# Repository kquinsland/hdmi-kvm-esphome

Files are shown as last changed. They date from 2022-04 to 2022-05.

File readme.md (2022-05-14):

# `uart_kvm` custom component for ESPHome

This custom component allows for basic control over a generic 8:1 HDMI2.0 KVM switch.
Specifically developed for model number [`PX-UHDKVM801-2.0`](https://www.aliexpress.com/item/1005003927404402.html).

Photos of the internals can be found [on my personal site](https://karlquinsland.com/hdmi-kvm-teardown-and-esphome/).

When working, you should get a device page in Home Assistant like this:

<!-- markdownlint-disable-next-line MD045 -->
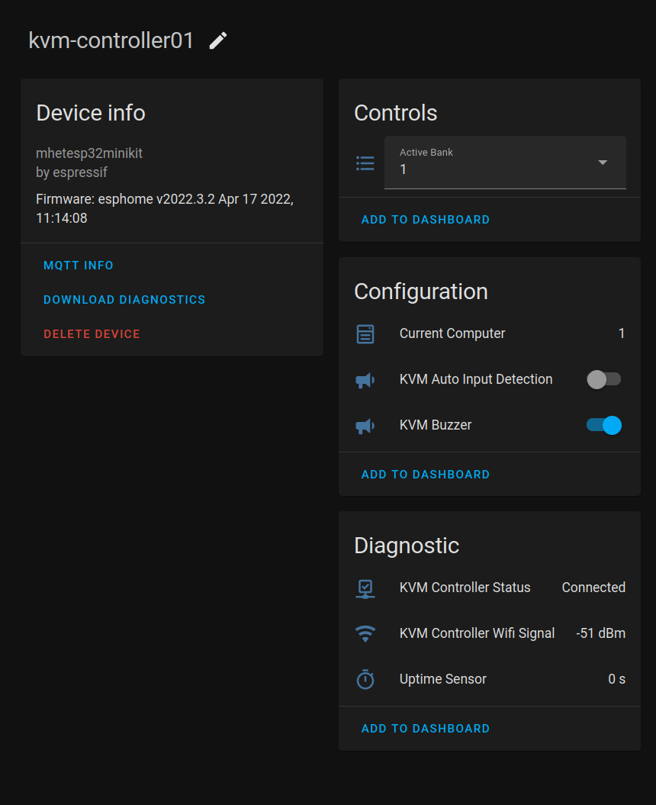
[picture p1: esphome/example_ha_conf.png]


## Using the component

**Note:** It is possible to get _basic_ control over the KVM without this custom component! ESPHome has _native_ support for _writing_ to a UART. If you only need to tell the KVM what to do then you can use the native [`uart.write`](https://esphome.io/components/uart.html#uart-write-action) call!

However, if  you also want to probe the KVM to get the current active input bank, you will need to _read_ from the UART which can't be done with the native UART component. That's where this custom component comes into play :).

To load this custom component in your ESPHome configuration, you need to use the [`external_components`](https://esphome.io/components/external_components.html) block like so:

```yaml
external_components:
  - source:
      type: git
      url: https://github.com/kquinsland/hdmi-kvm-esphome
    components: [ uart_kvm ]
```

If you have any issues, try to remove the local cache:

<!-- markdownlint-disable-file MD014 -->
```shell
$ rm -rf .esphome/external_components
```

## Example YAML

This is not a _complete_ YAML file for ESPHome but it does illustrate how to use the custom component and to control the KVM directly with `uart.write` for the various functionalities that the custom component does NOT implement:

```yaml
esphome:
  on_boot:
    priority: 600
    then:
      # Buzzer on is helpful for testing and to know when an automation triggers a change
      - switch.turn_on: sw_tmpl_buzzer
      # I do not want the KVM to automatically switch to any new active HDMI cable
      - switch.turn_off: sw_tmpl_auto_input

# See: https://esphome.io/components/external_components.html
# Will be cached in .esphome/external_components/
##
external_components:
  - source:
      type: git
      url: https://github.com/kquinsland/hdmi-kvm-esphome
    components: [ uart_kvm ]

##
# Expose a dropdown/select to the user via HA
# See: https://esphome.io/components/select/template.html
##
select:
  - platform: template
    id: tmpl_sel_active_port
    name: "Active Bank"
    optimistic: false
    # Create one option for each host the KVM is to control
    # You can use any string you like but the `set_active_bank()` requires an `int` so
    #   choose the strings in the select wisely!
    # Create an entry for each input bank you wish to be able to switch between.
    # E.G.: If you only have 5 hosts attached to an 8 bank switch, you can safely
    #   leave options for 6,7,8 off.
    # In testing the KVM silently ignores commands to switch to an input bank beyond
    #   what the switch supports. E.G.: telling an 8 port KVM to make bank 10 active 
    #    does nothing.
    ##
    options:
      - "1"
      - "2"
      - "3"
      - "4"
      - "5"
      - "6"
      - "7"
      - "8"
    set_action:
      then:
        lambda: |-
          // ESPHome/HA use strings in select components. atoi() fixes this for us :)
          int bank = atoi(x.c_str());
          id(kvm1).set_active_bank(bank);
    # We poll the uart to get the current port
    # Note: ESPHome polls get_active_bank() every several seconds. Unless we actively tell ESPHome to
    #   re-run this lambda as soon as the KVM active input bank changes, this value will lag behind reality
    lambda: |-
      int active = id(kvm1).get_active_bank();
      return to_string(active);

# The initial documentation that the seller provided did not define a way to inquire about buzzer active state or active input chase behavior so we can implement this with standard `uart.write` rather than in custom c++
switch:
  - platform: template
    id: sw_tmpl_buzzer
    name: "${friendly_name_short} Buzzer"
    icon: "mdi:bullhorn"
    entity_category: "config"
    device_class: "switch"
    optimistic: True
    # I don't know how to confirm the state of things so we must assume that sending the "off" command will be enough to turn it off. In testing, sending the "off" command is reliable.
    # If this was not the case, then we could change how things work in HA: instead of a switch
    #   the user will see 2 buttons: one for on, the other for off.
    assumed_state: false
    turn_on_action:
        # Note: the KVM does a short chirp to indicate that it is on
      - uart.write: [0xAA, 0xBB, 0x03, 0x02, 0x01, 0xEE]
    turn_off_action:
      - uart.write: [0xAA, 0xBB, 0x03, 0x02, 0x00, 0xEE]

  - platform: template
    id: sw_tmpl_auto_input
    name: "${friendly_name_short} Auto Input Detection"
    icon: "mdi:bullhorn"
    entity_category: "config"
    device_class: "switch"
    optimistic: True
    assumed_state: False
    turn_on_action:
      - uart.write: [0xAA, 0xBB, 0x03, 0x81, 0x01, 0xEE]
    turn_off_action:
      - uart.write: [0xAA, 0xBB, 0x03, 0x81, 0x00, 0xEE]

uart:
  # We want to impersonate the remote/handset by injecting via the HTX pin which is mapped to 17
  tx_pin: GPIO17
  # Likewise, if the motor controller sends anything to the remote, we _also_ want to hear it.
  rx_pin: GPIO16
  # bog standard 9600 8n1
  baud_rate: 9600

# Load up __init.py__
uart_kvm:
    id: kvm1
    active_bank:
      id: kvm1_bank
      name: "Current Computer"
      # We will expose this to HA through the template select above
      internal: false
      on_value:
        then:
          - lambda: |-
              // Tell ESPHome to refresh the value for the select so it does not lag by several seconds
              id(tmpl_sel_active_port).update();

```

### UART + Component

You will need a TTL <-> RS232 adapter hooked up to an ESP module. I have had a lot of trouble with the cheap MAX232 clone dongles on amazon so you absolutely should do basic loopback tests and confirm signal / voltage levels with an oscilloscope if you are having trouble getting this to work!

## PCB and enclosure

Because "scope-creep" is my middle name, I created a simple PCB and enclosure for an ESP32 module and `TTL` <-> `UART` module.
Details on both the PCB and enclosure can be found in the [`hardware`](./hardware/readme.md) folder.

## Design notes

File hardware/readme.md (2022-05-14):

# Hardware

The PCB and case are designed to be 1U in height. This also makes it pretty easy to secure to a basic power brick.
The PCB  can be powered via USB or via 12V DC. I wasn't sure if I was going to power the module off of one of the spare USB ports on the KVM or if I wanted to bundle the controller and main power supply so i could have one cable bundle going towards the KVM. I opted for the latter and decided to secure the enclosure to the power supply.

<!-- markdownlint-disable-next-line MD045 -->
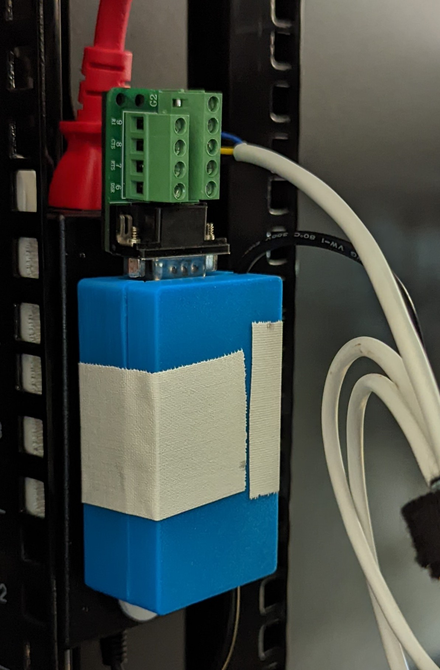
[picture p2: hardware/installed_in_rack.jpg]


The "DC out" cable leaves the enclosure right next to the DB9 port where the serial and power cables are combined with some cable ties before being routed to the KVM on the front of the rack.

## PCB

If you want to edit the pcb, the KiCad 6 files are included subject to [the license terms](../LICENSE.md).

The ESP32 module comes from [this](https://github.com/r0oland/ESP32_mini_KiCad_Library) library. Thanks to [r0oland](https://github.com/r0oland) for that library!

<!-- markdownlint-disable-next-line MD045 -->
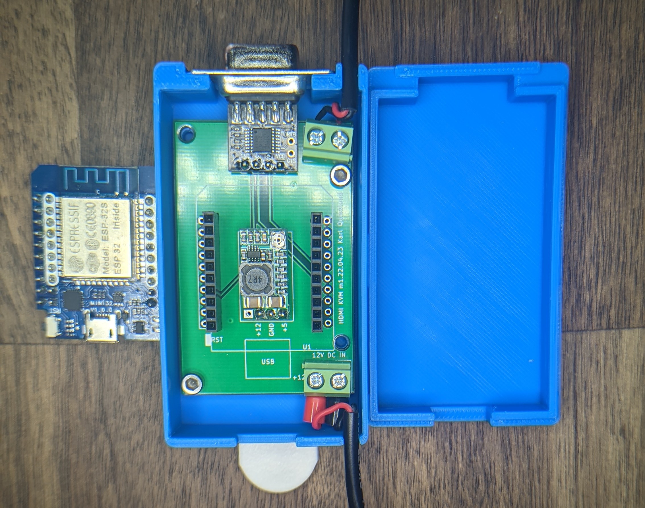
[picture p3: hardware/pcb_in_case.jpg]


### BOM

The PCB is secured to the enclosure with some 4mm M3 screws I had laying around.
The primary components on the PCB are:

- [D1 Mini style ESP32 chip](https://www.aliexpress.com/item/2251832633593063.html)
- [Configurable DC Buck converter module](https://www.aliexpress.com/item/32833398811.html). This steps the 12V dc from the KVM power supply down to the 5V for the ESP32 module.
- [Ultra Compact RS232 to TTL Converter with Female DB9 (3.3V to 5V)](https://www.amazon.com/gp/product/B00OPTOKI0/)

#### gerber

If you want to make zero changes, the [gerber files are included](./pcb/hdmi-kvm/export/2022.04.23.zip) and are subject to [the license terms](../LICENSE.md).

The gerber files / KiCad project are set up for use with JLCPCB but probably would work as-is with other PCB fab houses, too.

## Enclosure

It's not my best work but it works. I printed with my "fast, not accurate" profile so the snaps that are meant to keep the lid attached to the rest of the body don't work that well; this is the reason for the white tape in the picture.

You should be OK if you print slower but STEP files for both the [PCB](./pcb/hdmi-kvm/hdmi-kvm.step) and [enclosure](./enclosure/kvm-controller-enclosure.step) are included - subject to [the license terms](../LICENSE.md),

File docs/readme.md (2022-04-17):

Soon after ordering the switch, the seller provided me _basic_ information about how to control the KVM over RS232 and TCP:

[`01.png`](./from_seller/01.png)

[`02.jpg`](./from_seller/02.jpg)

I was able to plug the unique byte string `0xAA 0xBB 0x03` into google and found some additional documentation:

[`4x1-DVI-KVM-CommunicationProtocol.pdf`](./from_google/4x1-DVI-KVM-CommunicationProtocol.pdf)

[`16x1-hdmi-communication-protocol.pdf`](./from_google/16x1-hdmi-communication-protocol.pdf)

Only after I had done about 75% of the ESPHome custom component code did the seller provide me with [`8x1 KVM product integration information.zip`](./from_seller/8x1%20KVM%20product%20integration%20information.zip).

The `8x1 KVM product integration information` folder is the zip extracted. It contains additional software that appears to support more functionality than the basic serial documentation!

It shouldn't be super difficult to run the program and monitor the UART with either WireShark or a logic analyzer to figure out how to do the "program exclusive" things like:

- Change the IP address
- Change the LED display timeout

I don't need this functionality for my purposes so I'm not going to bother... 

I did dump the strings [`Controler.exe.strings`](./from_seller/8x1%20KVM%20product%20integration%20information/8x1-HDMI-Switch-Controler/Controler.exe.strings) and file hashes [`sha256sums.txt`](./from_seller/8x1%20KVM%20product%20integration%20information/8x1-HDMI-Switch-Controler/sha256sums.txt) just for posterity.

If you do manage to reverse engineer the magic UART commands to adjust TCP/IP config and other settings, please do share! PRs welcome :D.

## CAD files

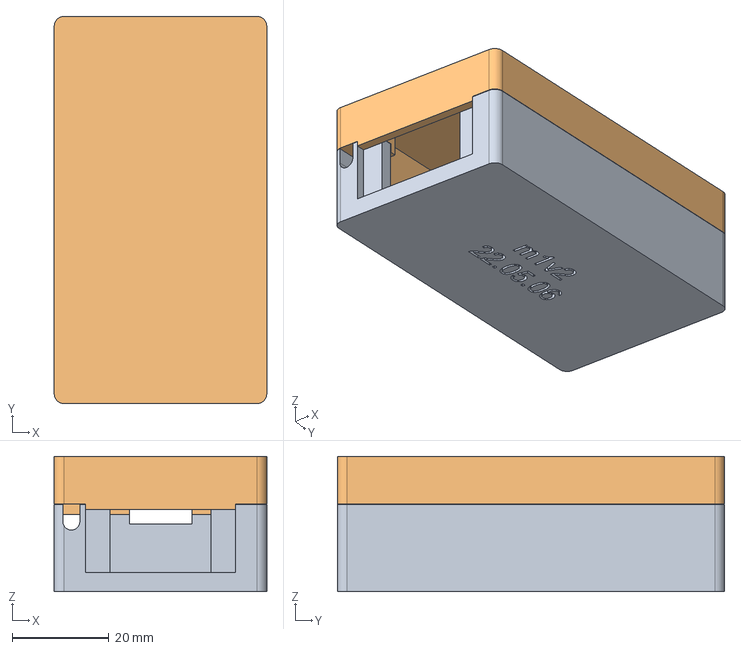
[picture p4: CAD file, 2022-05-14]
hardware/enclosure/kvm-controller-enclosure.step
44.0 x 80.1 x 28.0 mm

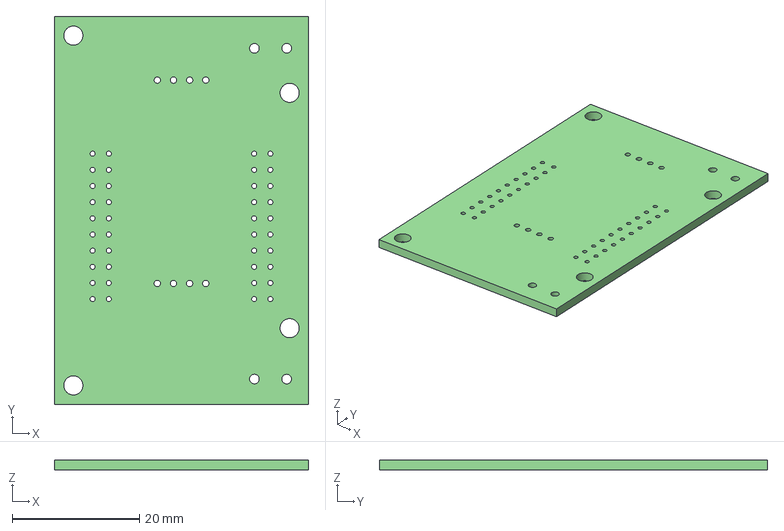
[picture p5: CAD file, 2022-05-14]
hardware/pcb/hdmi-kvm/hdmi-kvm.step
40.0 x 61.0 x 1.60 mm

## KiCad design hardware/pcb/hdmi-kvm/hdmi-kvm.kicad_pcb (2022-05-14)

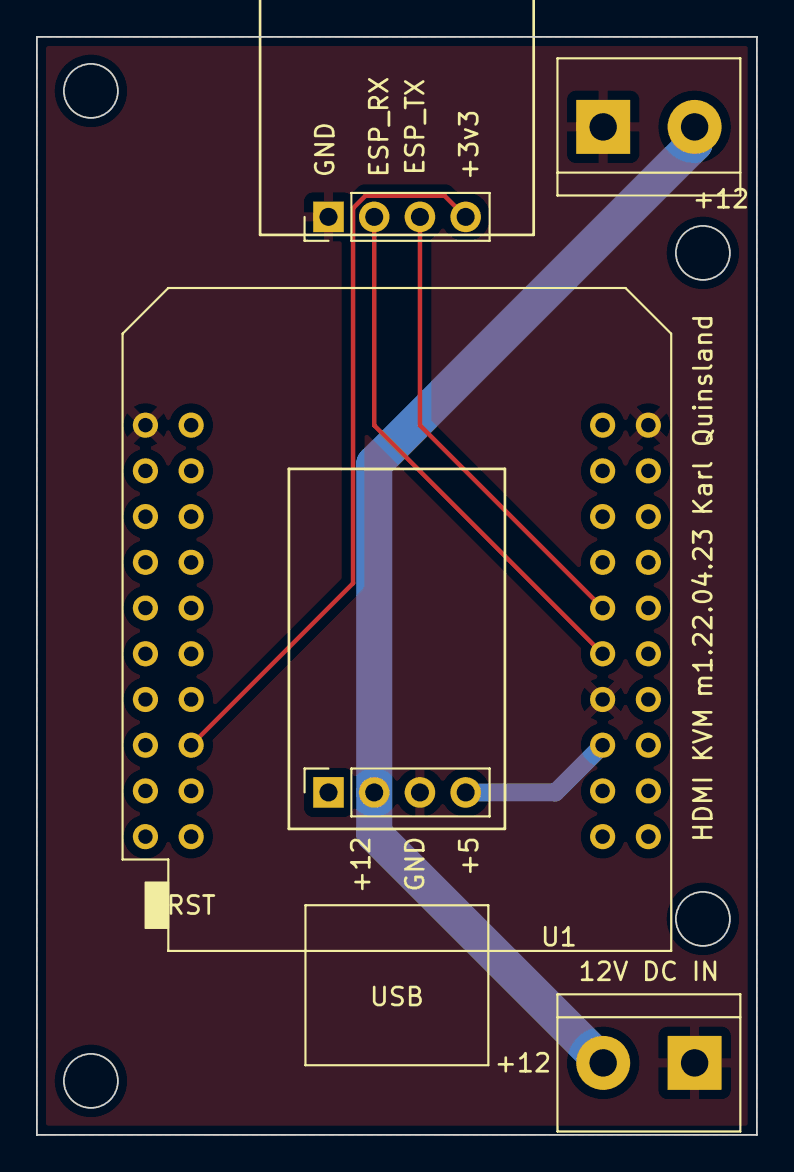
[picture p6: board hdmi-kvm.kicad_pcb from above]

Board: 2 copper layers, 40.0 x 61.0 mm, 5 parts (0 on the bottom side), 6 nets.

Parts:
J1: 12V DC IN; TerminalBlock_bornier-2_P5.08mm
J2: 12V DC OUT; TerminalBlock_bornier-2_P5.08mm
J3: DC_BUCK_CONN; PinSocket_1x04_P2.54mm_Vertical
J4: Conn_01x04_Male; PinHeader_1x04_P2.54mm_Vertical
U1: mini_esp32; ESP32_mini

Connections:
+3V3: J4.4, U1.16 (3V3)
+5V: J3.4, U1.35 (VCC_(USB))
+12V: J1.2, J2.2, J3.2
ESP_RX: J4.2, U1.31 (IO_16/D4)
ESP_TX: J4.3, U1.29 (IO_17/D3)
GND: J1.1, J2.1, J3.3, J4.1, U1.1 (GND), U1.22 (GND), U1.33 (GND)

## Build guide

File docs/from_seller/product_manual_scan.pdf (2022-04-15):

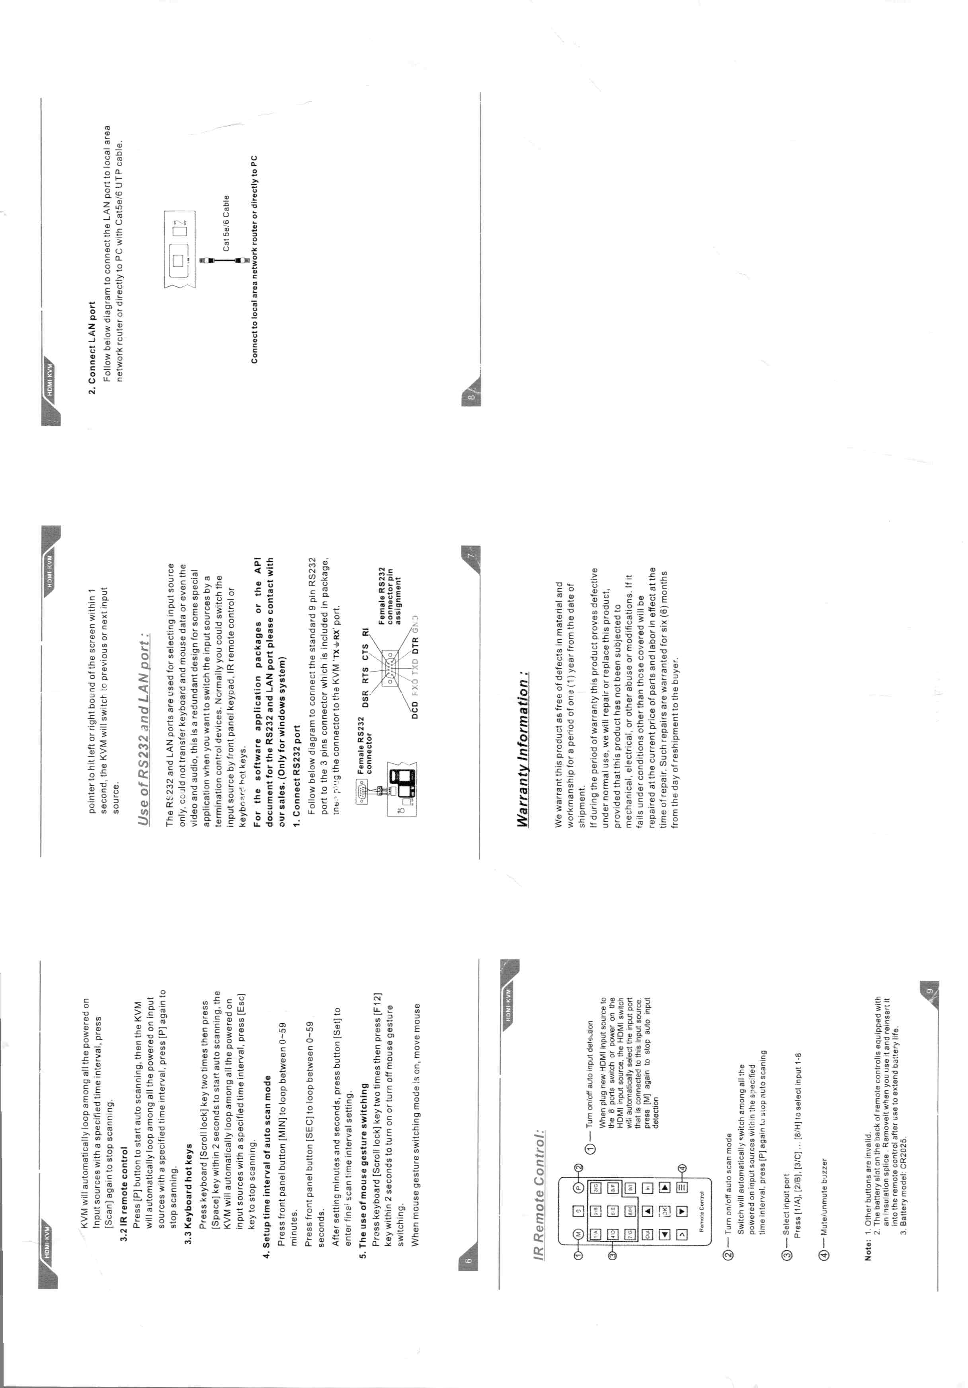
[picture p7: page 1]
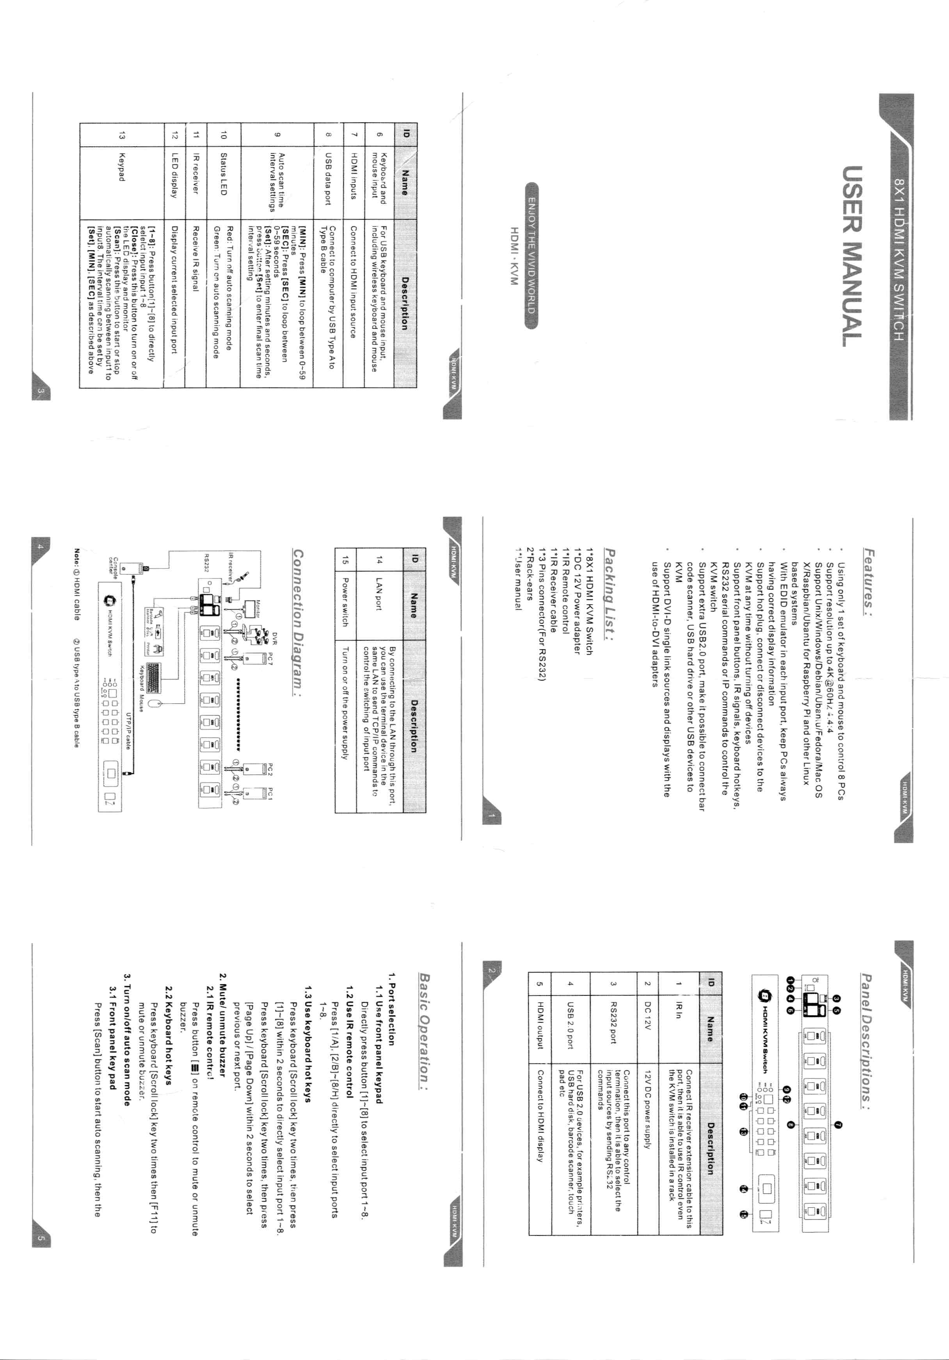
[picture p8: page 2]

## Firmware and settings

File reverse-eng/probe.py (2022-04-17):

"""
Trying to poke KVM / verify the protocol documentation from the seller
"""

import serial
import logging
logging.basicConfig(level=logging.DEBUG)


ser = serial.Serial('/dev/ttyUSB0')
ser.baudrate = 9600

"""
We can do a few things:

- get/set active computer
- get/set buzzer state
- get/set auto-input detection


Each packet is 6 bytes and shares a common header


0xAA 0xBB 0x03 0x01 0xXX 0xEE               Where XX is to change the port. not 0 indexed; screen 1 is 0x01
0xAA 0xBB 0x03 0x02 0xXX 0xEE               Where 0x01 is buzzer enabled
0xAA 0xBB 0x03 0x81 0xXX 0xEE               Where 0x01 enables auto input, 0x00 disables

0xAA 0xBB 0x03 0x10 0x00 0xEE               send this to GET the active port

and then the unit will REPLY with
0xAA 0xBB 0x03 0x11 0xXX 0xEE               where 0x00 will be the active PC. this IS zero indexed: 0x00 is port 1


"""
PKT_SIZE = 6
PREAMBLE = bytes([0xAA, 0xBB, 0x03])
POSTAMBLE = bytes([0xEE])

# This is the 8 port. Docs indicate that there might be a 4 and 16 port version, too.
NUMBER_OF_BANKS = 8


def _get_active_bank():
    """
    """
    _cmd = bytes([0x10, 0x00])
    _pkt = PREAMBLE + _cmd + POSTAMBLE
    logging.debug(f"sending: {_pkt}")
    ser.write(_pkt)

    reply = ser.read(size=PKT_SIZE)
    logging.debug(f"Here is reply: {reply}")

    # TODO basic validaion of the bytes we read
    _active_bank = int(_pkt[4])

    # Range stop is not inclusive and the protocol says that the switch will reply with 0 index
    if _active_bank in range(0, NUMBER_OF_BANKS):
        return _active_bank + 1
    else:
        logging.error("unknown bank")


def _set_active_bank(bank_number: int = 1) -> None:
    """
    """
    # When specifying the bank to use, protocol assumes NOT 0 indexed :/.
    if bank_number not in range(1, NUMBER_OF_BANKS+1):
        raise ValueError(f"Invalid bank number: {bank_number}")

    _cmd = bytes([1, bank_number])
    _pkt = PREAMBLE + _cmd + POSTAMBLE
    logging.debug(f"sending: {_pkt}")
    ser.write(_pkt)

    # I was just curious, but it looks like the unit WILL reply back. Sometimes with bytes and sometimes with ASCII
    #   messages of some log out!
    #       b'\x07\x1d\xaa\xbb\x03\x11'
    # I'm not super sure what this means... but good to know :)
    reply = ser.read(size=PKT_SIZE)
    logging.debug(f"Here is reply: {reply}")


def _set_buzzer_state(enabled: bool = False) -> None:
    """
    """
    # 0xAA 0xBB 0x03 0x02 0xXX 0xEE
    _cmd = bytes([0x02, enabled])
    _pkt = PREAMBLE + _cmd + POSTAMBLE
    logging.debug(f"sending: {_pkt}")
    ser.write(_pkt)
    # IN testing, I would sometimes see ASCII printed to the UART, too :/
    # Not after every command... but usually after this one. the ASCII is almost
    #       always some sort of 'i2c write error NN'


if __name__ == "__main__":
    logging.info(f"Inquiring about active port...")
    active_port = _get_active_bank()
    logging.info(f"active_port: {active_port}")

    desired_bank = 8
    logging.info(f"Setting desired_bank: {desired_bank}")
    _set_active_bank(desired_bank)

    logging.info(f"disable buzzer")
    _set_buzzer_state()

    logging.info(f"enable buzzer")
    _set_buzzer_state(True)
    logging.info(f"back to bank 1")
    _set_active_bank(1)
    ser.close()

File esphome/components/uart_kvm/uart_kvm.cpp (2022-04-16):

#include <math.h> /* round, floor, ceil, trunc */

#include "uart_kvm.h"
#include "esphome/core/log.h"

namespace esphome
{
      namespace uart_kvm
      {

            static const char *TAG = "uart_kvm";

            // Each packet is 6 bytes
            static const uint8_t PACKET_LEN = 6;

            void UartKvm::setup()
            {
                  // Nothing to do on setup
            }

            // void UartKvm::update()
            // {
            //       ESP_LOGD(TAG, "update");
            //       this->_inquire_active_bank();
            //       this->_read_kvm_reply();
            // }

            void UartKvm::loop()
            {
                  ESP_LOGD(TAG, "loop");
                  this->_inquire_active_bank();
                  this->_read_kvm_reply();
            }

            /*
                  Unfortunately, the KVM seems to also log ascii strings / errors to the UART. The errors seem to come from manual button presses
                        or IR remote signals. Since all packets to/from the device share a common pre/post amble and the values are

                        0xAA 0xBB 0x03 0x11 0xXX 0xEE

                  Where 0xXX will be somewhere between 0x00 and whatever the number of ports on the switch is.
            */
            void UartKvm::_read_kvm_reply()
            {
                  // Bytes as we read them
                  uint8_t response[PACKET_LEN];
                  uint8_t peeked;
                  uint8_t idx = 0;

                  while (this->available())
                  {
                        // Get the byte
                        this->read_byte(&peeked);
                        ESP_LOGD(TAG, "peeked[%i]: 0x%x \t %u", idx, peeked, peeked);
                        // I can't find any evidence that this OEM makes KVM with more than 16 / 0x0F ports
                        // We also care about the 0x11 byte as that seems to be the "active bank" message type
                        // Because the "led timeout" message type is 0x03 **and** 0x03 is a valid possible byte in the "active bank" message type
                        //    those packets will also 'pass' this filter for LED timeout values that are less tha 0x0F or equal to 0x11 or 0xEE
                        // We will filter those out later.
                        /////
                        if (peeked == 0xAA || peeked == 0xBB || (0x00 <= peeked && peeked <= 0x0F) || peeked == 0x11 || peeked == 0xEE)
                        {
                              response[idx] = peeked;
                              idx += 1;
                        }
                        // If we have 5 bytes, we can start to process: the first 3 will be preamble, byte 4 will be the type and byte 5 will be the value
                        if (idx == (PACKET_LEN - 1) && response[3] == 0x11)
                        {
                              ESP_LOGD(TAG, "EARLY EXIT; active bank!");
                              break;
                        }
                        else if (idx == (PACKET_LEN - 1))
                        {
                              ESP_LOGD(TAG, "EARLY EXIT; unknown type. Start over!");
                              idx = 0;
                        }
                  }

                  /*
                        I don't fully understand _why_, but sometimes the KVM will - UNPROMPTED - send packets that look like this:

                              [0] 0xaa    (170)
                              [1] 0xbb    (187)
                              [2] 0x3     (3)
                              [3] 0x3     (3)
                              [4] 0xaa    (170)
                              [5] 0xbb    (187)

                        From the documentation, it looks like the byte after the preamble (0xaa, 0xbb, 0x03) is the "packet type" and packet type
                              of 0x03 seems to be the LED timeout settings. The 5th byte is supposed to be the number of seconds on the timeout
                              but the value does not seem to match the behavior. In the above packet, the timeout looks like it is 170 seconds.

                        However, the little LED display on the front of the KVM that shows the active bank has been illuminated for the past several
                              hours that I have had it powered on for. 170 seconds is a little under 3 min and the LED display has absolutely been
                              lit for longer than 3 min!

                        We recognize but ignore packets of this type.

                        A packet where the 'type' byte is 0x11 indicates a "active port" message:

                              [0] 0xaa    (170)
                              [1] 0xbb    (187)
                              [2] 0x3     (3)
                              [3] 0x11    (16)
                              [4] 0x0     (0)               # KVM responds with 0 index. Add 1 to "match" the labeling on the device/remote
                              [5] 0xee    (238)


                        We are _very_ interested in these packets :).
                  */

                  switch (response[3])
                  {
                  case 0x03:
                        ESP_LOGD(TAG, "Got LED Timeout Message. Ignore value of: %i", response[4]);
                        return;
                  case 0x11:
                        ESP_LOGD(TAG, "Got Active Bank Message. Processing....");
                        _dump_packet(response);
                        // KVM responds with 0 index so we add 1 to map back to the way the remote/input buttons are labeled
                        this->active_bank_ = response[4] + 1;
                        ESP_LOGD(TAG, "active_bank: %i", this->active_bank_);

                        // We don't need to tell ESPHome that the value is still the same. We only bother when state changes :)
                        if (this->active_bank_sensor_->state != this->active_bank_)
                        {
                              this->active_bank_sensor_->publish_state(this->active_bank_);
                        }

                        return;
                  default:
                        ESP_LOGD(TAG, "Got unknown type of packet. Ignoring: %u ", response[3]);
                        break;
                  }
            }

            void UartKvm::_inquire_active_bank()
            {
                  // Ask the KVM what port is active
                  uint8_t pkt[] = {
                      0xAA,
                      0xBB,
                      0x03,
                      0x10,
                      0x00,
                      0xEE};
                  ESP_LOGD(TAG, "SEND: active bank?");
                  this->write_array(pkt, PACKET_LEN);
            }
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

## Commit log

2022-04-15 Initial commit
    Includes functional `probe.py` and docs from seller / found on the web
    Basic custom component passes initial esphome validation but does not yet compile
2022-04-16 More reliable polling implementation
    It was a lot of work to figure out how to filter the UART
    Now, the only problem is that I am not called often enough and there's too much noise on the UART so it takes ~10s / 2 calls before I get back packets that I expect.
    It might be worth going BACK to loop() as I can then send the "what active port?" message quickly...
    [uart_kvm.cpp]
2022-04-17 Tweak the readme
    includes a commented example yaml showing how to get the active bank via sensor and integrate with HA using select functions.
    Some basic functionality was removed from custom component and implemented with basic uart.write
2022-05-14 Add hardware documentation
    Misc spelling / linting
    License
    STEP/GERBER files and example images added
    [hdmi-kvm.kicad_pcb, hdmi-kvm.kicad_sch, hdmi-kvm.step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]
